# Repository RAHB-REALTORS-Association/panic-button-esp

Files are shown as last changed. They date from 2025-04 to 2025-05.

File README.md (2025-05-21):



<div align="center">
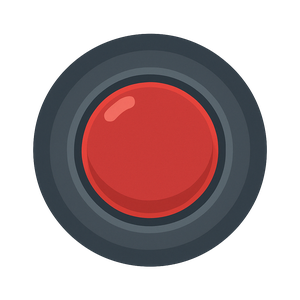
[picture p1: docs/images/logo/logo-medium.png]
Panic Button Logo
    
</div>
<div align="center">
    <h1>🔴 ESP32 Wi-Fi Panic Button</h1>
    <p>A standalone ESP32-based Wi-Fi panic button that sends email and/or webhook alerts when pressed. Designed for rapid deployment with a captive portal-based configuration interface, suitable for non-technical environments.</p>
</div>

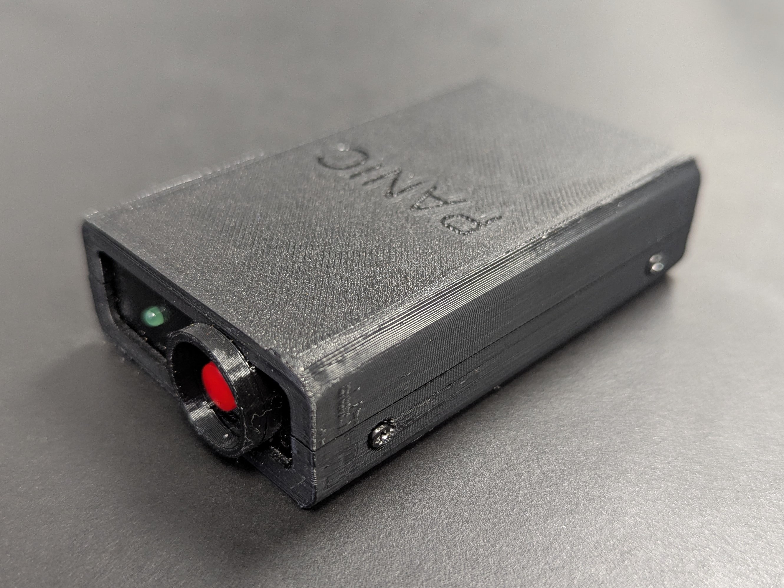
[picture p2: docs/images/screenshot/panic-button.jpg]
Panic button hardware


## 📚 Table of Contents

- [✨ Features](#-features)
- [🛠️ Hardware](#️-hardware)
- [🔌 Pinout](#-pinout)
- [📦 Libraries Used](#-libraries-used)
- [🚀 Getting Started](#-getting-started)
- [🔧 Web Interface](#-web-interface)
- [🔋 Battery Monitoring](#-battery-monitoring)
- [🌐 Webhook Integration](#-webhook-integration)
- [🔄 OTA Updates](#-ota-updates)
- [🔁 Resetting](#-resetting)
- [🖼️ UI Preview](#️-ui-preview)
- [🖨️ 3D-Printed Case](#️-3d-printed-case)
- [📄 License](#-license)

## ✨ Features

- Captive portal for Wi-Fi and alert configuration
- Email (SMTP) and/or webhook alerts when button is pressed
- EEPROM-stored settings with web-based update support
- Visual battery monitoring (gauge, percentage, and voltage)
- Responsive, mobile-friendly web interface
- Factory reset and test alert functionality
- Support for ESP32-C6 boards (like FireBeetle 2 ESP32-C6)
- Configuration validation to ensure at least one alert path is active

## 🛠️ Hardware

Optimized for:

### FireBeetle ESP32-C6
- [DFRobot FireBeetle 2 ESP32-C6 board](https://www.dfrobot.com/product-2771.html)
- Momentary push-button (GPIO 4)
- Onboard LED (GPIO 15)
- Battery voltage monitoring via A0 (GPIO 0)

## 🔌 Pinout

| Function | GPIO Pin |
|---|---|
| Panic Button | 4 |
| Status LED | 15 |
| Battery ADC | 0 |

## 📦 Libraries Used

- [ESP Mail Client](https://github.com/mobizt/ESP-Mail-Client)
- HTTPClient (for webhook functionality)
- WiFi
- WebServer
- DNSServer
- EEPROM

## 🚀 Getting Started

1. Flash the firmware using the **Arduino IDE**
2. If no config is stored, the device starts in **Setup Mode**:
   - Hosts an AP named `PanicAlarm_XXXX` (XXXX is part of the MAC address)
   - Password: `setupalarm`
   - Captive portal guides you through configuration
3. Once configured, the device connects to your Wi-Fi and enters **Normal Mode**

## 🔧 Web Interface

### Setup Mode
- Captive portal with pages for Wi-Fi, SMTP, webhook, and location setup
- Device enters this mode if config is missing or reset

### Normal Mode
- Live status dashboard with battery gauge and diagnostics
- Config page for updating any setting
- Alert testing tools for both email and webhook
- Factory reset with confirmation

## 🔋 Battery Monitoring

- Visual gauge with color coding:
  - Green: > 50%
  - Yellow: 25–50%
  - Red: < 25%
- Live percentage and voltage display
- Low battery alerts via email/webhook (if enabled)

## 🌐 Webhook Integration

Webhook alerts are JSON payloads with:
- `event` (e.g. `"panic_triggered"` or `"battery_low"`)
- `device_id`, `location`
- `battery_level`, `voltage`
- `ip`, `mac`
- `timestamp`

## 🔄 OTA Updates

This device supports automatic Over-The-Air firmware updates via the included OTA update server:

- Devices check for updates periodically
- Server verifies device identity and firmware compatibility
- Updates are downloaded and applied automatically
- No manual intervention required for managed devices

For hosting your own OTA update server, refer to the [OTA Server README](ota-server/README.md) for complete setup and usage instructions.

**Note:** OTA updates preserve all user configurations and settings.

## 🔁 Resetting

Access the reset page via the web UI to:
- Clear all config (Wi-Fi, SMTP, webhook, location)
- Restart in Setup Mode

## 🖼️ UI Preview

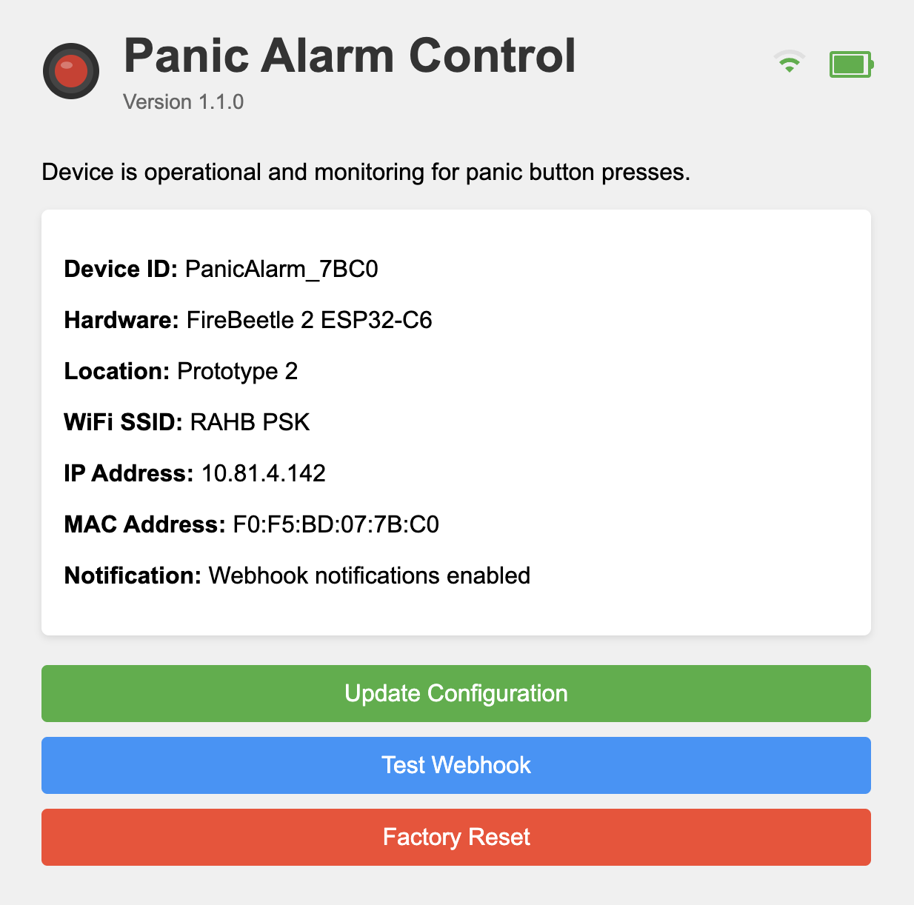
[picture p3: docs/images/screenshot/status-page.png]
Status Page


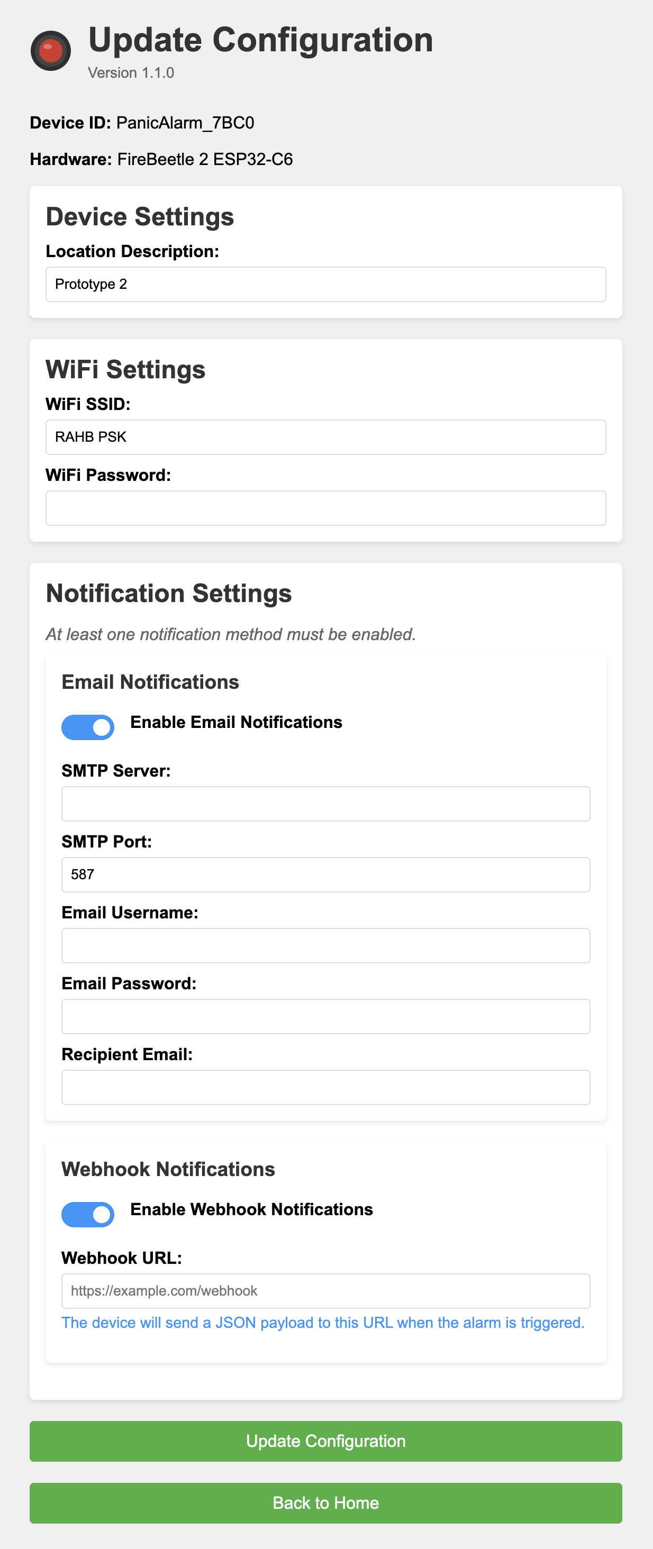
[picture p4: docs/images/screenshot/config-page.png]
Configuration Page


## 🖨️ 3D-Printed Case

This project includes a printable enclosure tailored for the FireBeetle ESP32-C6. All STL and 3MF files are located in the `case/v1/` directory:

- `panic_button_case.3mf` – complete project layout for slicers
- `case_back.stl`
- `case_bottom.stl`
- `case_front.stl`
- `case_top.stl`

### Recommended Slicer Settings

- **Material:** PLA, PETG, or similar
- **Layer Height:** 0.2 mm
- **Infill:** ≥ 15%
- **Supports:** Optional (recommended for top-bottom half alignment when screwed together)
- **Perimeters/Walls:** 2 or 3

The top and bottom shells include simple interlocking features. Use supports only if dimensional accuracy matters for your use case.

## 📄 License

**Firmware:** GPLv3 – see [LICENSE](LICENSE) for details.

**OTA Server:** AGPLv3 – see [ota-server/LICENSE](ota-server/LICENSE) for details.

**Case:** MIT License – see [case/LICENSE](case/LICENSE) for details.

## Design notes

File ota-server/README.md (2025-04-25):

# ESP32 OTA Update Server

A Flask-based server for managing Over-The-Air (OTA) updates for ESP32 devices.

## Features

- Secure device authentication
- Version comparison for update eligibility
- Configuration via JSON files and environment variables
- Admin API for device management
- Admin command-line tools
- Firmware checksum verification
- Detailed logging

## Directory Structure

```
ota-server/
├── app.py                  # Main Flask application
├── config.py               # Configuration management
├── utils.py                # Utility functions
├── admin_tools.py          # CLI for device management
├── config.json             # Server configuration
├── devices.json            # Device database
└── firmware/               # Firmware binary files
```

## Configuration

### Server Configuration

The server can be configured through:

1. The `config.json` file
2. Environment variables (prefixed with `OTA_SERVER_`)

Example `config.json`:

```json
{
  "shared_secret_key": "your-device-secret-key",
  "server_port": 5000,
  "server_host": "0.0.0.0",
  "debug_mode": false,
  "log_level": "INFO",
  "devices_file": "devices.json",
  "firmware_directory": "firmware",
  "admin_api_key": "change-admin-api-key-in-production"
}
```

Environment variable overrides:

```bash
export OTA_SERVER_SHARED_SECRET_KEY="my-secure-key"
export OTA_SERVER_SERVER_PORT=8080
export OTA_SERVER_ADMIN_API_KEY="admin-api-key"
```

### Device Management

Devices are stored in `devices.json` with the following format:

```json
{
  "AA:BB:CC:DD:EE:FF": {
    "device_id": "panic_button_01",
    "hardware_version": "1.0",
    "target_version": "1.2.1",
    "firmware_url": "http://example.com/firmware/PanicButton_v1.2.1.bin",
    "checksum": "5f4dcc3b5aa765d61d8327deb882cf99",
    "last_check": null,
    "last_update": null
  }
}
```

## Setup & Running

### Standard Installation

```bash
# Clone the repository
git clone https://github.com/yourusername/ota-update-server.git
cd ota-update-server

# Install dependencies
pip install -r requirements.txt
```

### Starting the Server (Standard)

```bash
python app.py
```

### Docker Installation

This project includes Docker and Docker Compose files for easy deployment.

```bash
# Clone the repository
git clone https://github.com/yourusername/ota-update-server.git
cd ota-update-server

# Create .env file from example
cp .env.example .env

# Edit the .env file with your configuration
nano .env

# Start the server
./start.sh
```

### Using Docker Compose Manually

```bash
# Start the server
docker-compose up -d

# View logs
docker-compose logs -f

# Stop the server
docker-compose down
```

## Device Integration

For your ESP32 device to use this OTA update server, it should:

1. Periodically check for updates using the `/api/firmware` endpoint
2. Include device information in the request (MAC, version, etc.)
3. Include an authentication token in the `X-Device-Auth` header
4. Download and install the new firmware if an update is available

Example ESP32 code snippet for authentication:

```cpp
String generateAuthToken() {
  // Remove colons and ensure uppercase
  String mac = WiFi.macAddress();
  mac.replace(":", "");
  mac.toUpperCase();
  
  // Combine with secret key
  String tokenStr = mac + SHARED_SECRET_KEY;
  
  // Simple hash (djb2 variant)
  uint32_t hash = 5381;
  for (int i = 0; i < tokenStr.length(); i++) {
    hash = ((hash << 5) + hash) + tokenStr.charAt(i);
  }
  
  // Convert to hex string
  char hexHash[9];
  sprintf(hexHash, "%08X", hash);
  return String(hexHash);
}
```

## Admin Tools

The `admin_tools.py` script provides a command-line interface for managing devices.

### Standard Usage

```bash
# List all registered devices
python admin_tools.py list

# Add a new device
python admin_tools.py add AA:BB:CC:DD:EE:FF --version 1.2.1 --firmware-file firmware/PanicButton_v1.2.1.bin

# Update a device
python admin_tools.py update AA:BB:CC:DD:EE:FF --version 1.3.0 --firmware-file firmware/PanicButton_v1.3.0.bin

# View device details
python admin_tools.py get AA:BB:CC:DD:EE:FF

# Calculate firmware checksum
python admin_tools.py checksum firmware/PanicButton_v1.2.1.bin

# Delete a device
python admin_tools.py delete AA:BB:CC:DD:EE:FF
```

### Docker Usage

Use the included `manage-devices.sh` script to manage devices when running in Docker:

```bash
# Make the script executable
chmod +x manage-devices.sh

# List all registered devices
./manage-devices.sh list

# Add a new device
./manage-devices.sh add AA:BB:CC:DD:EE:FF --version 1.2.1 --firmware-file firmware/PanicButton_v1.2.1.bin

# Other commands work the same way as in standard usage
./manage-devices.sh get AA:BB:CC:DD:EE:FF
```

## API Endpoints

### Device API

- `GET /api/firmware` - Check for firmware updates
  - Query parameters: `device_id`, `hardware`, `version`, `mac`
  - Header: `X-Device-Auth`

- `GET /firmware/<filename>` - Download firmware binary

### Admin API

All admin API endpoints require the `X-Admin-API-Key` header.

- `GET /admin/devices` - List all devices
- `GET /admin/devices/<mac_address>` - Get device information
- `POST /admin/devices` - Add a new device
- `PUT /admin/devices/<mac_address>` - Update device information
- `DELETE /admin/devices/<mac_address>` - Delete a device

## Security Considerations

- Always use HTTPS in production
- Use a strong, unique `shared_secret_key` for device authentication
- Set a secure `admin_api_key` for admin API access
- Consider using a reverse proxy (nginx, etc.) for production deployments
- Store `devices.json` in a secure location

## License

This project is licensed under the AGPL-3.0 License. See the [LICENSE](LICENSE) file for details.

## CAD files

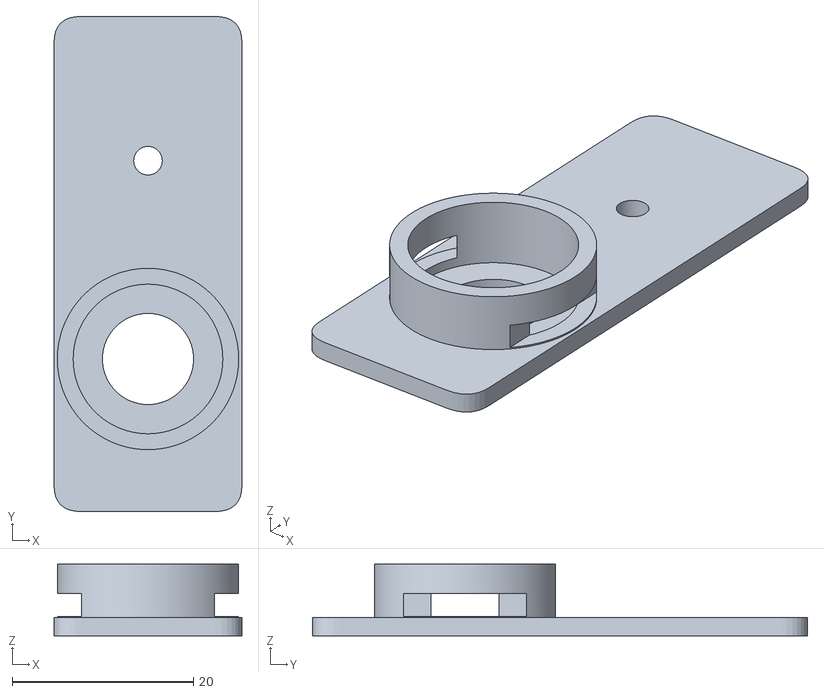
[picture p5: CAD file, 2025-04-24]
case/v1/case_front.stl
20.7 x 54.6 x 7.89

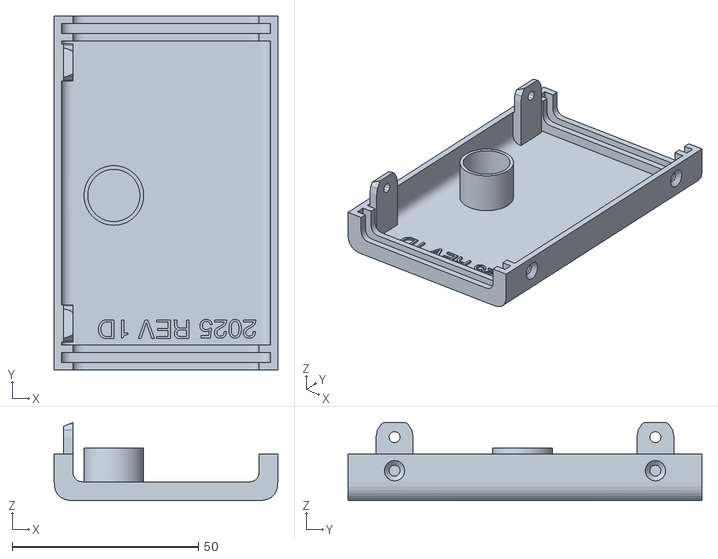
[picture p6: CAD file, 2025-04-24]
case/v1/case_top.stl
60.0 x 95.0 x 20.9

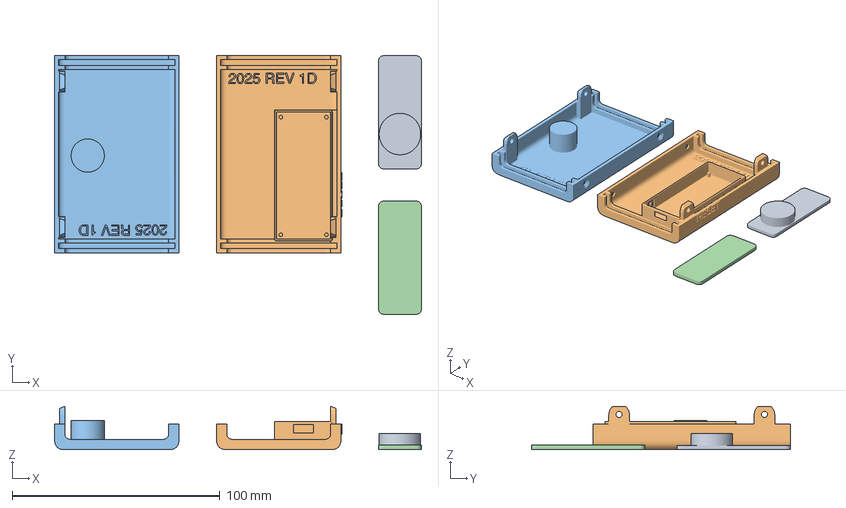
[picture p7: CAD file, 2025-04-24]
case/v1/panic_button_case.3mf
176.7 x 124.7 x 20.9 mm
panic_button_case_rev1d_buttoncap.stl
panic_button_case_rev1d_base.stl
panic_button_case_rev1d_top.stl
panic_button_case_rev1d_endcap.stl

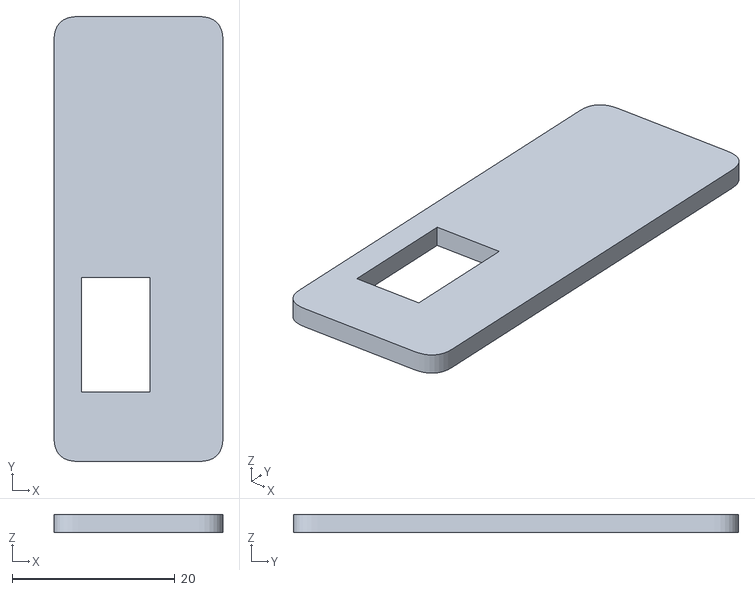
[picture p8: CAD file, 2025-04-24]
case/v1/case_back.stl
20.7 x 54.6 x 2.26

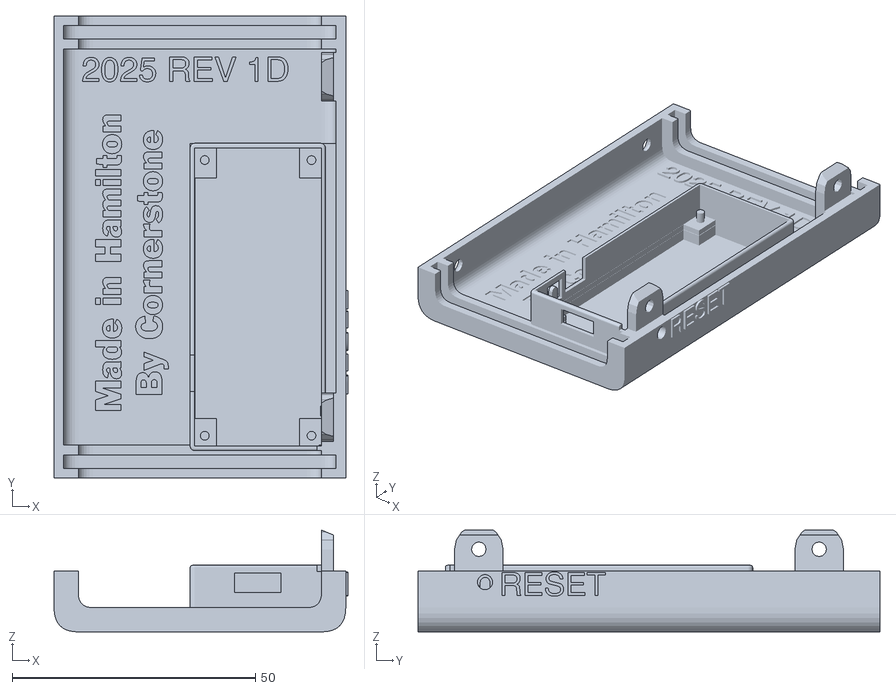
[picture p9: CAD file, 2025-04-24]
case/v1/case_bottom.stl
60.5 x 95.0 x 20.9

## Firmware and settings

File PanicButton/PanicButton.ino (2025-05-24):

#include <WiFi.h>
#include <DNSServer.h>
#include <WebServer.h>
#include <EEPROM.h>
#include <ESP_Mail_Client.h>
#include <HTTPClient.h>
#include <Update.h>
#include <ArduinoJson.h>

// Constants
#define EEPROM_SIZE 710
#define CONFIG_FLAG_ADDR 0
#define SSID_ADDR 10
#define PASS_ADDR 80
#define EMAIL_SERVER_ADDR 150
#define EMAIL_PORT_ADDR 220
#define EMAIL_USER_ADDR 224
#define EMAIL_PASS_ADDR 294
#define EMAIL_RECIPIENT_ADDR 364
#define LOCATION_ADDR 434
#define WEBHOOK_URL_ADDR 504
#define WEBHOOK_ENABLED_ADDR 674
#define EMAIL_ENABLED_ADDR 675

#define ENABLE_BATTERY_MONITORING 1  // Set to 0 to disable battery monitoring
#define ENABLE_DEEP_SLEEP 1          // Set to 0 to disable deep sleep functionality
//#define BUTTON_PIN 0                 // ESP32 Dev Module onboard button
//#define BUTTON_PIN 13                // ESP32 Dev Module suitable GPIO pin
#define BUTTON_PIN 4                 // FireBeetle suitable GPIO pin (prod)
//#define BUTTON_PIN 5                 // FireBeetle suitable GPIO pin (proto 2)
//#define LED_PIN 2                    // ESP32 Dev Module onboard LED
//#define LED_PIN 15                   // FireBeetle onboard LED
#define LED_PIN 5                    // FireBeetle suitable GPIO pin (prod)
//#define LED_PIN 23                   // FireBeetle suitable GPIO pin (proto 2)
#define BATTERY_PIN 0                // A0 on FireBeetle ESP32-C6
#define DNS_PORT 53
#define WEBSERVER_PORT 80
#define SENDGRID_HOST "smtp.sendgrid.net"
#define CONFIG_FLAG 0xAA
#define uS_TO_S_FACTOR 1000000       // Conversion factor for micro seconds to seconds
#define TIME_TO_SLEEP  60            // Time ESP32 will sleep (in seconds)
#define BATT_SAMPLES 10              // Battery read averaging
#define BATT_MAX_VOLTAGE 4.2         // Maximum battery voltage (fully charged)
#define BATT_MIN_VOLTAGE 3.2         // Minimum battery voltage (depleted)
#define WIFI_CHECK_INTERVAL 30000    // Check WiFi signal every 30 seconds

// OTA Update configuration
#define OTA_CHECK_INTERVAL 86400000    // Check for updates once per day (in ms)
#define OTA_SERVER_URL "https://your-update-server.com/api" // <<<--- Needs real URL
#define OTA_UPDATE_KEY "your-device-secret-key" // <<<--- Needs real shared secret

// Global variables
bool isConfigMode = false;
String configSSID = "PanicAlarm_"; // Will be updated with MAC address
const char* configPassword = "setupalarm"; // Optional: Set a password for the AP mode
String wifi_ssid = "";
String wifi_password = "";
String email_server = "";
int email_port = 0;
String email_username = "";
String email_password = "";
String email_recipient = "";
String device_location = "";
String webhook_url = "";
bool webhook_enabled = false;
bool email_enabled = true; // Flag to enable email (default to true for backward compatibility)
bool alarmTriggered = false;
bool lowBatteryAlertSent = false; // Flag to track if low battery alert was sent
unsigned long lastDebounceTime = 0;
unsigned long debounceDelay = 50;
int buttonState = HIGH;
int lastButtonState = HIGH;
float batteryVoltage = 0.0;
int batteryPercentage = 0;
unsigned long lastBatteryCheck = 0;
String hardwarePlatform = ""; // Store hardware platform info
int rssi = 0;                 // WiFi signal strength in dBm
String signalQuality = "";    // Signal quality rating
unsigned long lastWifiCheck = 0; // Last time WiFi signal was checked
String firmwareVersion = "1.3.7"; // Firmware version - <<<--- MAKE SURE THIS IS UPDATED WITH EACH RELEASE

// OTA update variables
unsigned long lastOtaCheck = 0;
bool updateInProgress = false;
String newFirmwareVersion = ""; // Stores version found by check, even if update fails

// Forward declarations
void loadConfig();
void saveConfig(String ssid, String password, String server, int port,
                String username, String emailpass, String recipient, String location,
                String webhook, bool webhook_en, bool email_en);
void blinkLED(int times, int delayms);
void goToDeepSleep();
void startConfigMode();
bool connectToWiFi();
void checkButton();
void triggerAlarm();
bool sendWebhook();
bool sendEmailAlert();
bool sendLowBatteryAlert();
bool sendLowBatteryWebhook();
bool sendLowBatteryEmail();
void sendSetupCompleteAlert();
float getBatteryVoltage();
bool isLowBattery();
void checkBatteryStatus();
void checkWiFiSignal();
String getSignalQuality(int rssi);
String generateUniqueSSID();
int calculateBatteryPercentage(float voltage);

// OTA Function declarations
bool checkForUpdates();
String generateAuthToken();
bool downloadAndUpdate(String firmwareUrl, String expectedChecksum);
String urlEncode(String str);
int compareVersions(String v1, String v2);

// Web handlers
void handleRoot();
void handleSetup();
void handleNormalRoot();
void handleConfigPage();
void handleUpdate();
void handleTestEmail();
void handleTestWebhook();
void handleReset();
void handleCss();
void handleCheckUpdate();

WebServer server(WEBSERVER_PORT);
DNSServer dnsServer;
SMTPSession smtp;

// Setup function
void setup() {
  Serial.begin(115200);

  // Initialize pins
  pinMode(BUTTON_PIN, INPUT_PULLUP);
  pinMode(LED_PIN, OUTPUT);
  digitalWrite(LED_PIN, LOW);

  #if ENABLE_BATTERY_MONITORING
  pinMode(BATTERY_PIN, INPUT);
  analogReadResolution(12); // 12-bit ADC resolution
  #endif

  // Determine hardware platform
  #if defined(CONFIG_IDF_TARGET_ESP32C6)
    hardwarePlatform = "FireBeetle 2 ESP32-C6";
  #elif defined(CONFIG_IDF_TARGET_ESP32C3)
    hardwarePlatform = "FireBeetle 2 ESP32-C3";
  #elif defined(CONFIG_IDF_TARGET_ESP32E)
    hardwarePlatform = "FireBeetle 2 ESP32-E";
  #else
    hardwarePlatform = "ESP32 Dev Module";
  #endif

  Serial.print("Hardware Platform: ");
  Serial.println(hardwarePlatform);

  // Generate unique SSID based on MAC
  configSSID = generateUniqueSSID();
  Serial.print("Generated unique SSID: ");
  Serial.println(configSSID);

  #if ENABLE_BATTERY_MONITORING
  // Read initial battery voltage using onboard divider (×2)
  int mV = analogReadMilliVolts(BATTERY_PIN);
  batteryVoltage = (mV * 2) / 1000.0;
  batteryPercentage = calculateBatteryPercentage(batteryVoltage);
  Serial.print("Initial battery voltage: ");
  Serial.print(batteryVoltage);
  Serial.print(" V (");
  Serial.print(batteryPercentage);
  Serial.println("%)");
  #else
  // Set default values when battery monitoring is disabled
  batteryVoltage = 4.0;
  batteryPercentage = 100;
  #endif

  // Initialize EEPROM
  EEPROM.begin(EEPROM_SIZE);

  #if ENABLE_DEEP_SLEEP
  // Configure deep sleep wakeup
  uint64_t bitmask = 1ULL << BUTTON_PIN;
  esp_sleep_enable_ext1_wakeup(bitmask, ESP_EXT1_WAKEUP_ANY_LOW);
  #endif

  // Check if device is configured
  if (EEPROM.read(CONFIG_FLAG_ADDR) != CONFIG_FLAG) {
    Serial.println("No configuration found. Starting setup mode...");
    startConfigMode();
  } else {
    loadConfig();
    if (connectToWiFi()) {
      Serial.println("Connected to WiFi. Starting normal operation.");
      checkWiFiSignal(); // Get initial signal strength
      blinkLED(3, 200);
    } else {
      Serial.println("Failed to connect to WiFi. Starting setup mode...");
      startConfigMode();
    }
  }
}

// Generate unique SSID using the last 4 characters of MAC address
String generateUniqueSSID() {
  String baseName = "PanicAlarm_";
  
  // Initialize WiFi to ensure MAC is available
  WiFi.mode(WIFI_STA);
  delay(100); // Short delay to ensure WiFi is initialized
  
  uint8_t mac[6];
  WiFi.macAddress(mac);
  
  // Convert the last two bytes of MAC to HEX string
  char macStr[5];
  sprintf(macStr, "%02X%02X", mac[4], mac[5]);
  
  return baseName + macStr;
}

// Calculate battery percentage from voltage
int calculateBatteryPercentage(float voltage) {
  if (voltage >= BATT_MAX_VOLTAGE) {
    return 100;
  } else if (voltage <= BATT_MIN_VOLTAGE) {
    return 0;
  } else {
    // Linear approximation between min and max voltage
    float percentage = ((voltage - BATT_MIN_VOLTAGE) / (BATT_MAX_VOLTAGE - BATT_MIN_VOLTAGE)) * 100.0;
    return (int)percentage;
  }
}

// Evaluate WiFi signal strength and return quality rating
String getSignalQuality(int rssi) {
  if (rssi > -55) {
    return "Excellent";
  } else if (rssi > -70) {
    return "Good";
  } else if (rssi > -80) {
    return "Okay";
  } else if (rssi > -90) {
    return "Poor";
  } else {
    return "Very Poor";
  }
}

// Check WiFi signal strength
void checkWiFiSignal() {
  if (WiFi.status() == WL_CONNECTED) {
    rssi = WiFi.RSSI();
    signalQuality = getSignalQuality(rssi);
    Serial.print("WiFi signal strength: ");
    Serial.print(rssi);
    Serial.print(" dBm (");
    Serial.print(signalQuality);
    Serial.println(")");
  } else {
    rssi = -100; // Set to minimum value if not connected
    signalQuality = "Disconnected";
  }
}

// Main loop
void loop() {
  if (isConfigMode) {
    // Handle DNS and web server in config mode
    dnsServer.processNextRequest();
    server.handleClient();
  } else {
    // Normal operation mode
    checkButton();
    
    #if ENABLE_BATTERY_MONITORING
    // Check battery status periodically
    checkBatteryStatus();
    #endif
    
    // Check WiFi signal periodically
    if (millis() - lastWifiCheck > WIFI_CHECK_INTERVAL) {
      lastWifiCheck = millis();
      checkWiFiSignal();
    }
    
    // Check for OTA updates periodically
    if (millis() - lastOtaCheck > OTA_CHECK_INTERVAL && !updateInProgress && WiFi.status() == WL_CONNECTED) {
      lastOtaCheck = millis();
      Serial.println("Checking for firmware updates...");
      checkForUpdates();
    }

    server.handleClient(); // Continue handling web requests
    
    // Add short delay to prevent watchdog reset
    delay(10);
  }
}

// Check battery status periodically
void checkBatteryStatus() {
  #if ENABLE_BATTERY_MONITORING
  if (millis() - lastBatteryCheck > 60000) { // Check every minute
    lastBatteryCheck = millis();
    batteryVoltage = getBatteryVoltage();
    batteryPercentage = calculateBatteryPercentage(batteryVoltage);
    Serial.print("Battery voltage: ");
    Serial.print(batteryVoltage);
    Serial.print(" V (");
    Serial.print(batteryPercentage);
    Serial.println("%)");
    
    if (isLowBattery() && !lowBatteryAlertSent) {
      blinkLED(5, 50); // Fast blink to indicate low battery
      // Send low battery notification once per boot
      if (WiFi.status() == WL_CONNECTED) {
        if (sendLowBatteryAlert()) {
          lowBatteryAlertSent = true; // Set flag to prevent repeated alerts
          Serial.println("Low battery alert sent. No more alerts will be sent until reboot.");
        }
      }
    }
  }
  #endif
}

// Get battery voltage
float getBatteryVoltage() {
  #if ENABLE_BATTERY_MONITORING
  long total_mV = 0;
  for (int i = 0; i < BATT_SAMPLES; i++) {
    total_mV += analogReadMilliVolts(BATTERY_PIN);
    delay(5);
  }
  float avg_mV = total_mV / BATT_SAMPLES;
  return (avg_mV * 2) / 1000.0;  // Compensate for onboard voltage divider
  #else
  return 4.0; // Return a default value when disabled
  #endif
}

// Check if battery is low
bool isLowBattery() {
  #if ENABLE_BATTERY_MONITORING
  return batteryPercentage < 50;
  #else
  return false; // Never report low battery when monitoring is disabled
  #endif
}

// Start configuration mode with AP and captive portal
void startConfigMode() {
  isConfigMode = true;
  
  // Set up Access Point
  WiFi.mode(WIFI_AP);
  WiFi.softAP(configSSID.c_str(), configPassword);
  
  Serial.print("AP IP address: ");
  Serial.println(WiFi.softAPIP());
  
  // Configure DNS server for captive portal
  dnsServer.start(DNS_PORT, "*", WiFi.softAPIP());
  
  // Set up web server routes
  server.on("/", HTTP_GET, handleRoot);
  server.on("/setup", HTTP_POST, handleSetup);
  server.on("/style.css", HTTP_GET, handleCss);
  server.onNotFound(handleRoot); // Captive portal redirect
  
  server.begin();
  Serial.println("HTTP server started");
  
  // Blink LED to indicate config mode
  blinkLED(5, 100);
}

// Connect to saved WiFi network
bool connectToWiFi() {
  if (wifi_ssid.length() == 0) return false;
  
  WiFi.mode(WIFI_STA);
  WiFi.begin(wifi_ssid.c_str(), wifi_password.c_str());
  
  Serial.print("Connecting to WiFi");
  
  int attempts = 0;
  while (WiFi.status() != WL_CONNECTED && attempts < 20) {
    delay(500);
    Serial.print(".");
    attempts++;
  }
  
  if (WiFi.status() == WL_CONNECTED) {
    Serial.println("");
    Serial.print("Connected to WiFi: ");
    Serial.println(wifi_ssid);
    Serial.print("IP address: ");
    Serial.println(WiFi.localIP());
    
    // Get initial signal strength
    rssi = WiFi.RSSI();
    signalQuality = getSignalQuality(rssi);
    Serial.print("WiFi signal strength: ");
    Serial.print(rssi);
    Serial.print(" dBm (");
    Serial.print(signalQuality);
    Serial.println(")");
    
    // Enable WiFi power saving for battery life
    WiFi.setSleep(true);
    
    // Set up web server routes for normal operation
    server.on("/", HTTP_GET, handleNormalRoot);
    server.on("/config", HTTP_GET, handleConfigPage);
    server.on("/update", HTTP_POST, handleUpdate);
    server.on("/test", HTTP_GET, handleTestEmail);
    server.on("/test-webhook", HTTP_GET, handleTestWebhook);
    server.on("/reset", HTTP_GET, handleReset);
    server.on("/check-update", HTTP_GET, handleCheckUpdate); // Added for OTA
    server.on("/style.css", HTTP_GET, handleCss);
    
    server.begin();
    return true;
  } else {
    Serial.println("");
    Serial.println("Failed to connect to WiFi");
    return false;
  }
}

// Check button state and send alarm if pressed
void checkButton() {
  int reading = digitalRead(BUTTON_PIN);
  
  if (reading != lastButtonState) {
    lastDebounceTime = millis();
  }
  
  if ((millis() - lastDebounceTime) > debounceDelay) {
    if (reading != buttonState) {
      buttonState = reading;
      
      if (buttonState == LOW) { // Button pressed (active LOW with pull-up)
        Serial.println("Panic button pressed!");
        triggerAlarm();
      }
    }
  }
  
  lastButtonState = reading;
}

// Trigger the alarm and send notification
void triggerAlarm() {
  if (alarmTriggered) return; // Prevent multiple triggers in rapid succession
  
  alarmTriggered = true;
  digitalWrite(LED_PIN, HIGH); // Turn on LED to indicate alarm
  
  bool notificationSent = false;
  
  // Try to send webhook if enabled
  if (webhook_enabled && webhook_url.length() > 0) {
    if (sendWebhook()) {
      Serial.println("Webhook notification sent successfully");
      notificationSent = true;
    } else {
      Serial.println("Failed to send webhook notification");
    }
  }
  
  // Try to send email if enabled
  if (email_enabled && email_server.length() > 0 && email_recipient.length() > 0) {
    if (sendEmailAlert()) {
      Serial.println("Email notification sent successfully");
      notificationSent = true;
    } else {
      Serial.println("Failed to send email notification");
    }
  }
  
  if (notificationSent) {
    // Blink to indicate success
    for (int i = 0; i < 5; i++) {
      digitalWrite(LED_PIN, LOW);
      delay(100);
      digitalWrite(LED_PIN, HIGH);
      delay(100);
    }
  } else {
    // Different blink pattern for failure
    for (int i = 0; i < 2; i++) {
      digitalWrite(LED_PIN, LOW);
      delay(500);
      digitalWrite(LED_PIN, HIGH);
      delay(500);
    }
  }
  
  // Reset alarm state after delay
  delay(5000);
  digitalWrite(LED_PIN, LOW);
  alarmTriggered = false;
}
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

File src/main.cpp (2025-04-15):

#include <Arduino.h>
#include <WiFi.h>  // Added WiFi library include
#include "config.h"
#include "network.h"
#include "storage.h"
#include "notifications.h"

// Global variables for button handling
bool alarmTriggered = false;
unsigned long lastDebounceTime = 0;
unsigned long debounceDelay = 50;
int buttonState = HIGH;
int lastButtonState = HIGH;

// Sleep control variables - device will not sleep for the first 5 minutes after boot
unsigned long startupTime = 0;
// Minimum runtime before allowing sleep (in milliseconds)
const unsigned long MIN_RUNTIME_BEFORE_SLEEP = 300000; // 300 seconds = 5 minutes

// Function declarations
void checkButton();
void triggerAlarm();

#if defined(ESP32_C6) && HAS_BATTERY_MONITORING && ENABLE_DEEP_SLEEP
void goToDeepSleep();
#endif

void setup() {
  Serial.begin(115200);
  
  // Record startup time
  startupTime = millis();
  Serial.println("Device starting up. Will not sleep for the first 300 seconds.");
  
  // Initialize pins
  pinMode(BUTTON_PIN, INPUT_PULLUP);
  initLED();

  #if HAS_BATTERY_MONITORING
  initBattery();
  #endif
  
  // Initialize EEPROM
  initStorage();
  
  #if defined(ESP32_C6) && ENABLE_DEEP_SLEEP
  // Configure deep sleep wakeup for FireBeetle
  uint64_t bitmask = 1ULL << BUTTON_PIN;
  esp_sleep_enable_ext1_wakeup(bitmask, ESP_EXT1_WAKEUP_ANY_LOW);
  #endif
  
  // Check if device is configured
  if (!isConfigured()) {
    Serial.println("No configuration found. Starting setup mode...");
    startConfigMode();
  } else {
    loadConfig();
    if (connectToWiFi()) {
      Serial.println("Connected to WiFi. Starting normal operation.");
      blinkLED(3, 200); // Success indicator
    } else {
      Serial.println("Failed to connect to WiFi. Starting setup mode...");
      startConfigMode();
    }
  }
}

void loop() {
  if (isInConfigMode()) {
    // Handle DNS and web server in config mode
    handleConfigMode();
  } else {
    // Normal operation mode
    checkButton();
    
    #if HAS_BATTERY_MONITORING && ENABLE_DEEP_SLEEP
    checkBatteryStatus();
    
    // Check if we can go to sleep yet
    unsigned long currentTime = millis();
    if (currentTime - startupTime > MIN_RUNTIME_BEFORE_SLEEP) {
      // After the minimum runtime, we can consider going to sleep
      // Check if it's time for a regular sleep cycle (every 60 seconds by default)
      static unsigned long lastSleepCheck = 0;
      if (currentTime - lastSleepCheck > TIME_TO_SLEEP * 1000) {
        lastSleepCheck = currentTime;
        Serial.println("Regular sleep cycle - going to sleep");
        goToDeepSleep();
      }
    } else {
      // Log remaining time until sleep is allowed (every 30 seconds)
      if (currentTime % 30000 == 0) { 
        Serial.print("Sleep disabled for ");
        Serial.print((MIN_RUNTIME_BEFORE_SLEEP - (currentTime - startupTime)) / 1000);
        Serial.println(" more seconds");
      }
    }
    #endif
    
    // Continue handling web requests
    handleWebRequests();
    
    // Add short delay to prevent watchdog reset
    delay(10);
  }
}

// Check button state and send alarm if pressed
void checkButton() {
  int reading = digitalRead(BUTTON_PIN);
  
  if (reading != lastButtonState) {
    lastDebounceTime = millis();
  }
  
  if ((millis() - lastDebounceTime) > debounceDelay) {
    if (reading != buttonState) {
      buttonState = reading;
      
      if (buttonState == LOW) { // Button pressed (active LOW with pull-up)
        Serial.println("Panic button pressed!");
        triggerAlarm();
      }
    }
  }
  
  lastButtonState = reading;
}

// Trigger the alarm and send notification
void triggerAlarm() {
  if (alarmTriggered) return; // Prevent multiple triggers in rapid succession
  
  alarmTriggered = true;
  setLED(true); // Turn on LED to indicate alarm
  
  if (sendEmailAlert()) {
    Serial.println("Alarm notification sent successfully");
    // Blink to indicate success
    for (int i = 0; i < 5; i++) {
      setLED(false);
      delay(100);
      setLED(true);
      delay(100);
    }
  } else {
    Serial.println("Failed to send alarm notification");
    // Different blink pattern for failure
    for (int i = 0; i < 2; i++) {
      setLED(false);
      delay(500);
      setLED(true);
      delay(500);
    }
  }
  
  // Reset alarm state after delay
  delay(5000);
  setLED(false);
  alarmTriggered = false;
}

#if defined(ESP32_C6) && HAS_BATTERY_MONITORING && ENABLE_DEEP_SLEEP
// Enter deep sleep mode to save battery (FireBeetle specific)
void goToDeepSleep() {
  // Check if we've been running long enough to allow sleep
  if (millis() - startupTime <= MIN_RUNTIME_BEFORE_SLEEP) {
    Serial.println("Not sleeping yet, minimum runtime not reached");
    return;
  }
  
  // Ensure any pending operations are completed
  if (WiFi.status() == WL_CONNECTED) {
    // Disconnect WiFi cleanly before sleep
    WiFi.disconnect(true);
    delay(100);
  }
  
  // Configure wake timer (TIME_TO_SLEEP is defined in firebeetle_config.h)
  esp_sleep_enable_timer_wakeup(TIME_TO_SLEEP * uS_TO_S_FACTOR);
  
  Serial.println("Going to deep sleep for " + String(TIME_TO_SLEEP) + " seconds");
  Serial.flush(); // Make sure serial output completes
  delay(100);
  esp_deep_sleep_start();
}
#endif

extern "C" void lwip_hook_ip6_input(void) {
  // No-op implementation to satisfy linker
}

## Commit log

2025-04-09 Complete Rewrite for ESP32
2025-04-14 Port to PlatformIO, modularize code
    [min_spiffs.csv]
2025-04-14 Force ESP32C6 support for PlatformIO
2025-04-15 Update default button pin # for FireBeetle
2025-04-15 Back to Arduino
    [min_spiffs.csv]
2025-04-16 Add battery gauge and logo
2025-04-16 Arduino links in docs
2025-04-16 Fix webhook, support Slack, Teams, Google Chat, Discord.
    [PanicButton.ino]
2025-04-24 upload case model files
    [case_back.stl, case_bottom.stl, case_front.stl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]
2025-04-24 fix model export error
    [case_front.stl]
2025-04-24 Create LICENSE for case
2025-04-24 MIT license for case
2025-04-24 Add compile flag for battery monitor
2025-05-24 feat: Enhance notification and testing features
    This commit introduces several improvements to the PanicButton firmware:
    1. **SendGrid Email Handling:**
    - Modifies email sending logic to correctly use SendGrid when `email_server` is set to "smtp.sendgrid.net".
    - It now uses "apikey" as the SMTP username and the configured user email address as the `From:` address, with the API key as the password.
    2. **Setup Completion Notification:**
    - Adds a new notification (email and/or webhook) that is sent after the initial device setup and configuration.
    - This notification includes device configuration, hardware information, and IP address, similar to regular alerts.
    3. **Consis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
    [PanicButton.ino]
2025-05-25 Fix: Relocate setup complete notification to after device restart.
    The notification for setup completion was previously sent before the device
    restarted, often leading to failure if network settings were changed or
    the network was not immediately available.
    This change renames the notification function to `sendDeviceReadyNotification`
    and moves its invocation to the main `setup()` function, after a successful
    WiFi connection.
    A new compile-time macro `SEND_NOTIFICATION_ON_RESTART` (defaulting to 1, enabled)
    has been added to control whether this notification is sent on every
    successful boot and network connection. If set to 0 or commented out,
    the notification will be disabled.
    Notificati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

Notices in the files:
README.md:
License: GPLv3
